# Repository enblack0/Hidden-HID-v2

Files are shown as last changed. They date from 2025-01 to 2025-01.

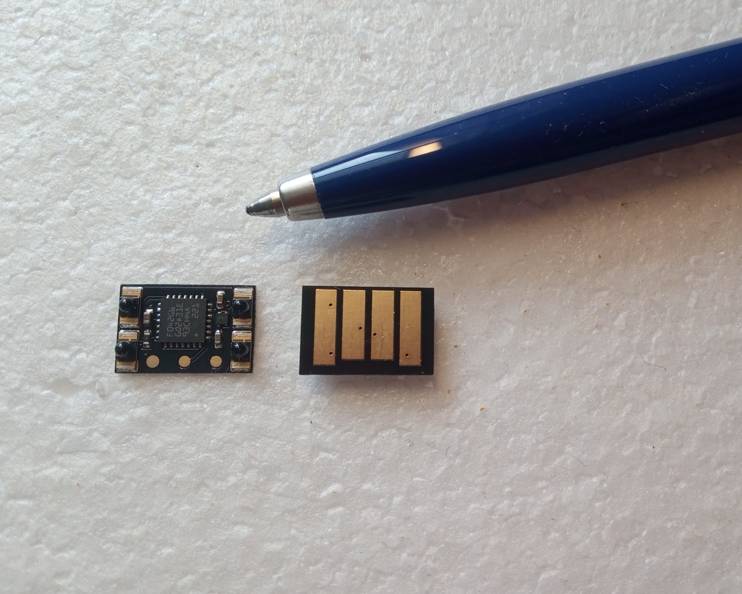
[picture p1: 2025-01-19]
photos/cover-cropped.jpg

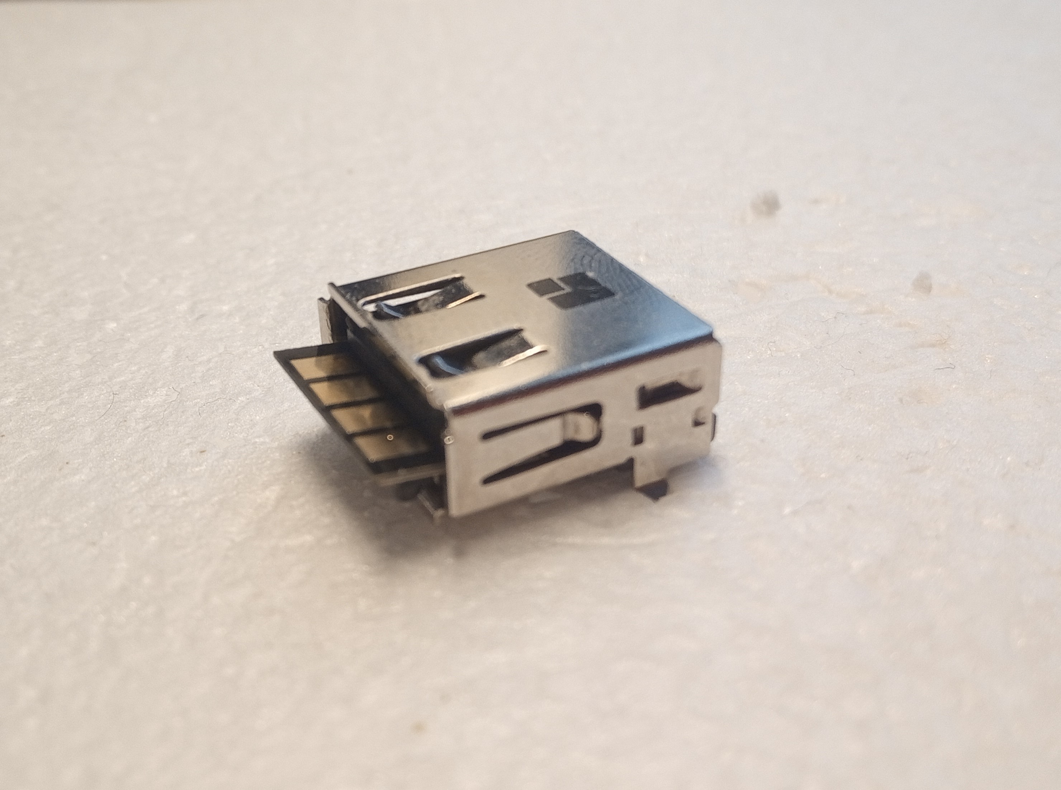
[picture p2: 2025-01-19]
photos/IMG_20250118_131920_344.jpg

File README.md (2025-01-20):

# Hidden-HID-v2
Hidden HID v2 is a tiny USB rubber ducky that can be concealed entirely inside the USB port. I have implemented various hardware improvements compared to v1.

These include: 
1. Removal of SWD programming pins to rely only on STs internal USB bootloader, which avoids the need to painstakingly solder the PCB to the STLink debugger every time I want to change the program. Now it is only necessary to bridge the BOOT0 test pad (middle) with 3V3 to select bootloader, or with GND to select application (see image below). After connecting BOOT0 to 3V3, the STM32 can then be programmed by inserting into the USB port and using the STCubeProgrammer tool to download the hex file. 
2. Layout changes to enable easier assembly of the spacer elements
3. Switching the spacer elements from LEDs with no electrical function to IR phototransistors which also provide a simple on-off remote control. This allows the device to be remotely armed and disarmed once inserted.

rev2-bot 

connect BOOT0 to GND to run application or with 3V3 to reprogram

KiCad files can be found under /KiCad, gerber and BOM separately under /Fabrication.
Under /STM32 I have uploaded a basic test firmware. This firmware waits for an IR signal, then opens a terminal and echoes hello world. You may need to tweak the paths a little to get it running on your system. 

If you are interested in purchasing this PCB, I have uploaded it to the PCBWay community. Here you can order either the bare PCB or the assembled PCB directly: https://www.pcbway.com/project/shareproject/Hidden_HID_an_invisible_USB_Rubber_Ducky_3a8cd27f.html

Also check out the project write-up on hackaday: https://hackaday.io/project/202218-hidden-hid-v2-worlds-smallest-rubber-ducky

cover-cropped



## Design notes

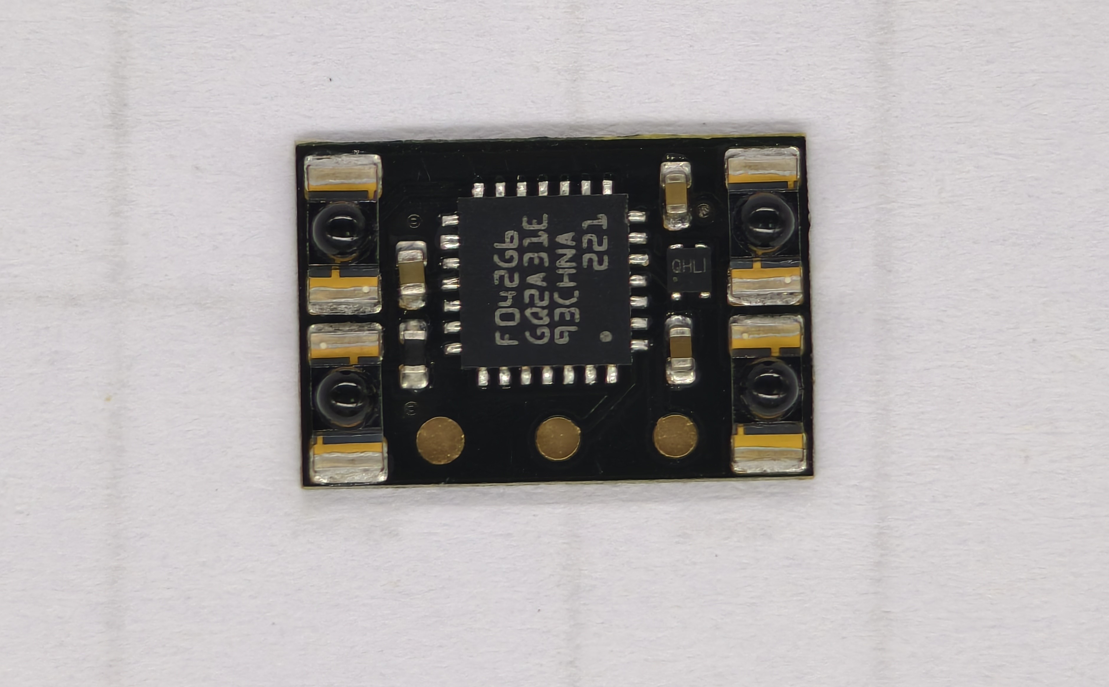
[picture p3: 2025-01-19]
photos/bot-hr.jpg

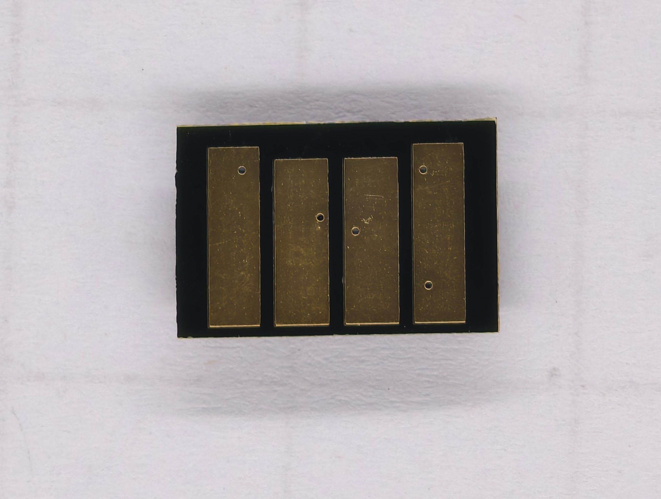
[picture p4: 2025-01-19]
photos/top-hr.jpg

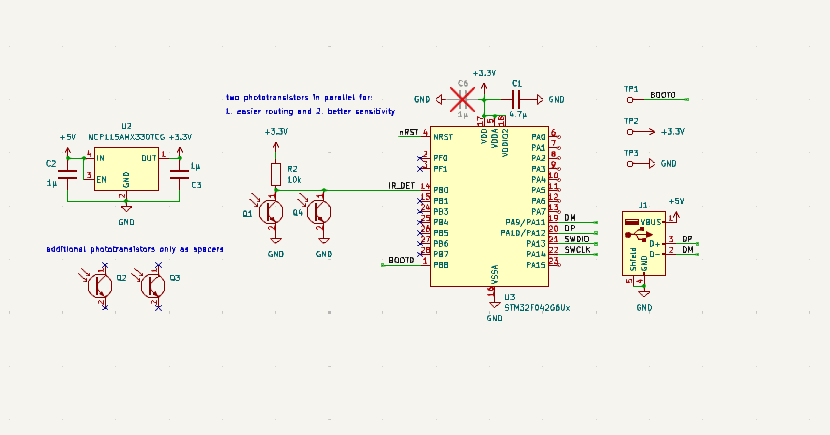
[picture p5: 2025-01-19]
photos/Screenshot 2025-01-18 160303.png

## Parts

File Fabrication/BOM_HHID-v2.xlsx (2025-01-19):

Item | Designator | Quantity | Manufacturer | Mfg Part # | Description / Value | Package / Footprint | Type | Mouser Part # | Digikey Part # | Notes
1 | C1 | 1 |  |  | CAP CER 4.7µF 10V X5R/X7R | 0402 | SMD
2 | C2, C3 | 2 |  |  | CAP CER 1µF 16V X5R/X7R | 0402 | SMD
3 | R2 | 1 |  |  | RES 10k 1% | 0402 | SMD
4 | Q1, Q2, Q3, Q4 | 4 | Würth Elektronik | 1541201NC3060 | Phototransistor IR 940nm | 1206 | SMD | 710-1541201NC3060
5 | U3 | 1 | STMicroelectronics | STM32F042G6U6 | ARM Microcontrollers - MCU Mainstream Arm Cortex-M0+ MCU 32 Kbytes Flash | UFQFPN-28 | SMD | 511-STM32F042G6U6
6 | U2 | 1 | onsemi | NCP115AMX330TCG | LDO 3.3V 300mA | XDFN-4 | SMD | 863-NCP115AMX330TCG

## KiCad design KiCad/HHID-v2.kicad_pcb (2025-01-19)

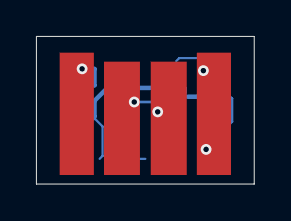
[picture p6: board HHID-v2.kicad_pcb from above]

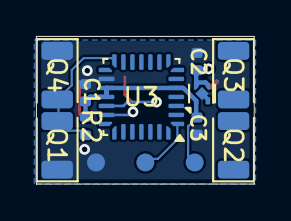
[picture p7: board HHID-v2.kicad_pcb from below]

Board: 2 copper layers, 12.1 x 8.2 mm, 14 parts (13 on the bottom side), 7 nets.

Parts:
C1: 4.7µ; C_0402_1005Metric_noSS
C2, C3: 1µ; C_0402_1005Metric_noSS
J1: USB_A; usb-PCB
Q1, Q2, Q3, Q4: Würth 1541201NC3060; LED_1206_3216Metric_IPC_C
R2: 2k2; R_0402_1005Metric_noSS
TP1, TP2, TP3: TestPoint_Pad_D0.8mm
U2: NCP115AMX330TCG; OnSemi_XDFN4-1EP_1.0x1.0mm_EP0.52x0.52mm
U3: STM32F042G6Ux; QFN-28_4x4mm_P0.5mm

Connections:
+3.3V: C1.2, C3.2, R2.1, TP2.1, U2.1 (OUT), U3.5 (VDDA), U3.17 (VDD), U3.18 (VDDIO2)
+5V: C2.1, J1.1 (VBUS), U2.3 (EN), U2.4 (IN)
/BOOT0: TP1.1, U3.1 (PB8)
/DM: J1.2 (D-), U3.19 (PA9/PA11)
/DP: J1.3 (D+), U3.20 (PA10/PA12)
/IR_DET: Q1.1 (C), Q4.1 (C), R2.2, U3.14 (PB0)
GND: C1.1, C2.2, C3.1, J1.4 (GND), Q1.2 (E), Q4.2 (E), TP3.1, U2.2 (GND), U2.5 (GND), U3.16 (VSSA)

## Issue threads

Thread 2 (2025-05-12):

How to compile?

todbot, 2025-05-12:
Hi! This is a really neat project.  But I cannot figure out how to get STMCubeIDE to load up the source and compile it?  I'm pretty experienced with other ARM-based chips (SAMD, RP2040, ESP32), but not STM32.  I've installed the latest STM32CubeIDE and have tried opening up or importing various parts of this repo with no success.  What's the process?  Is there a Makefile or similar instead?

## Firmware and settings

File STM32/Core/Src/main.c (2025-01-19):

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
/* Includes ------------------------------------------------------------------*/
#include "main.h"
#include "usb_device.h"
#include "stdio.h"
#include "../../STM32CubeIDE/Middlewares/USB_Device_Library/usbd_hid_ext.h"


/* USER CODE BEGIN PD */
#define KEYBOARD //also need to define in usbd_hid.c!

#define MOD_ALT_LEFT 0x04
#define WINKEY_LEFT 0xE3
#define ENTER 0x28
#define SPACE 0x2C
#define COMMA 0x36
#define DOT 0x37
#define K_A 0x04
#define K_B 0x05
#define K_C 0x06
#define K_D 0x07
#define K_E 0x08
#define K_G 0x0A
#define K_H 0x0B
#define K_I 0x0C
#define K_L 0x0F
#define K_M 0x10
#define K_N 0x11
#define K_O 0x12
#define K_P 0x13
#define K_R 0x15
#define K_S 0x16
#define K_T 0x17
#define K_U 0x18
#define K_V 0x19
#define K_W 0x1A

#define K_F8 0x41
#define CAPSLOCK 0x39
/* USER CODE END PD */

ADC_HandleTypeDef hadc;

/* USER CODE BEGIN PV */
volatile uint8_t capslock_;
/* USER CODE END PV */

void SystemClock_Config(void);
static void MX_GPIO_Init(void);
static void MX_ADC_Init(void);
/* USER CODE BEGIN PFP */
extern USBD_HandleTypeDef hUsbDeviceFS;
void Keyboard_SendChars(uint8_t mod, uint8_t *buf);
void Keyboard_SendSingleChar(uint8_t mod, uint8_t val);
void Keyboard_SendHelloWorld();
void Keyboard_WaitCapsLock();
void Keyboard_ShowPassword();
void Keyboard_TestADC();

typedef struct
{
	uint8_t MODIFIER;
	uint8_t RESERVED;
	uint8_t KEYCODE1;
	uint8_t KEYCODE2;
	uint8_t KEYCODE3;
	uint8_t KEYCODE4;
	uint8_t KEYCODE5;
	uint8_t KEYCODE6;
} kbdHID;

kbdHID keyboardHID = {0,0,0,0,0,0,0,0};
/* USER CODE END PFP */

/* USER CODE BEGIN 0 */
void Keyboard_SendChars(uint8_t mod, uint8_t *buf)
	{
		keyboardHID.MODIFIER = mod;
		keyboardHID.KEYCODE1 = buf[0];
		keyboardHID.KEYCODE2 = buf[1];
		keyboardHID.KEYCODE3 = buf[2];
		keyboardHID.KEYCODE4 = buf[3];
		keyboardHID.KEYCODE5 = buf[4];
		keyboardHID.KEYCODE6 = buf[5];
		USBD_HID_SendReport(&hUsbDeviceFS, &keyboardHID, sizeof (keyboardHID));
		HAL_Delay (50);

		//release
		keyboardHID.MODIFIER = 0x00;
		keyboardHID.KEYCODE1 = 0x00;
		keyboardHID.KEYCODE2 = 0x00;
		keyboardHID.KEYCODE3 = 0x00;
		keyboardHID.KEYCODE4 = 0x00;
		keyboardHID.KEYCODE5 = 0x00;
		keyboardHID.KEYCODE6 = 0x00;
		USBD_HID_SendReport(&hUsbDeviceFS, &keyboardHID, sizeof (keyboardHID));
		HAL_Delay (50);
	}

	void Keyboard_SendSingleChar(uint8_t mod, uint8_t val)
	{
		keyboardHID.MODIFIER = mod;
		keyboardHID.KEYCODE1 = val;
		USBD_HID_SendReport(&hUsbDeviceFS, &keyboardHID, sizeof (keyboardHID));
		HAL_Delay (50);

		keyboardHID.MODIFIER = 0;
		keyboardHID.KEYCODE1 = 0;
		USBD_HID_SendReport(&hUsbDeviceFS, &keyboardHID, sizeof (keyboardHID));
		HAL_Delay(50);
	}

	//open terminal and send hello world
	void Keyboard_SendHelloWorld()
	{
	    uint8_t buf[6] = {0,0,0,0,0,0};
		//winkey+r to open run utility
	    buf[0] = WINKEY_LEFT; buf[1] = K_R;
		Keyboard_SendChars(0,buf);
		HAL_Delay(100);
		//open command prompt
		buf[0] = K_C; buf[1] = K_M; buf[2] = K_D; buf[3] = ENTER;
		Keyboard_SendChars(0,buf);
		HAL_Delay(600);
		buf[0] = K_E; buf[1] = K_C; buf[2] = K_H; buf[3] = K_O; buf[4] = SPACE;
		Keyboard_SendChars(0,buf);
		buf[0] = K_H; buf[1] = K_E; buf[2] = K_L; buf[3] = 0x00; buf[4] = 0x00;
		Keyboard_SendChars(0,buf);
		buf[0] = K_L; buf[1] = K_O; buf[2] = SPACE;
		Keyboard_SendChars(0,buf);
		buf[0] = K_W; buf[1] = K_O; buf[2] = K_R; buf[3] = K_L; buf[4] = K_D; buf[5] = ENTER;
		Keyboard_SendChars(0,buf);
	}

	//check that PC is unlocked before executing by setting capslock and waiting for user to turn it off
	void Keyboard_WaitCapsLock()
	{
		//try to set capslock until it succeeds
		while(capslock_==0) {
		  Keyboard_SendSingleChar(0x00, CAPSLOCK);
		  HAL_Delay(1000);
		}
		while(capslock_==1); //wait here for user to turn off capslock
		HAL_Delay(2000);
	}

	//send ALT+F8 shortcut to display passwords being typed in
	void Keyboard_ShowPassword()
	{
		keyboardHID.MODIFIER = MOD_ALT_LEFT;
		keyboardHID.KEYCODE1 = K_F8;
		USBD_HID_SendReport(&hUsbDeviceFS, &keyboardHID, sizeof (keyboardHID));
		HAL_Delay (250);

		keyboardHID.MODIFIER = 0;
		keyboardHID.KEYCODE1 = 0;
		USBD_HID_SendReport(&hUsbDeviceFS, &keyboardHID, sizeof (keyboardHID));
		HAL_Delay(50);
	}

	//send current ADC value over USB
	void Keyboard_TestADC()
	{
		uint8_t buf[6] = {0,0,0,0,0,0};
		uint16_t adc_val = 0;
		char adc_str[6];
		HAL_ADC_Start(&hadc);
		HAL_ADC_PollForConversion(&hadc,100);
		adc_val = HAL_ADC_GetValue(&hadc);
		HAL_ADC_Stop(&hadc);
		sprintf(adc_str, "%04d", adc_val);
		for(uint8_t i=0;i<4;i++){
		  if(adc_str[i]==0x30) buf[i]=0x27; //zero case
		  else buf[i] = adc_str[i] - 0x13; //translate other digits from ASCII to HID
		  Keyboard_SendSingleChar(0,buf[i]);
		}
		Keyboard_SendSingleChar(0,ENTER);
		HAL_Delay(1000);
	}
/* USER CODE END 0 */

/**
  * @brief  The application entry point.
  * @retval int
  */
int main(void)
{

  /* MCU Configuration--------------------------------------------------------*/

  /* Reset of all peripherals, Initializes the Flash interface and the Systick. */
  HAL_Init();

  /* Configure the system clock */
  SystemClock_Config();

  /* USER CODE BEGIN SysInit */
  capslock_ = 0;
  /* USER CODE END SysInit */

  /* Initialize all configured peripherals */
  MX_GPIO_Init();
  MX_USB_DEVICE_Init();
  MX_ADC_Init();
  /* USER CODE BEGIN 2 */
  HAL_Delay(3000);
  Keyboard_WaitCapsLock();
  //HAL_Delay(10000);

  //get reference ADC value without IR by averaging 16 ADC readings over first 8 seconds
  uint16_t adc_val_ini = 0;
  for(uint8_t i = 0; i<16; i++) {
	HAL_Delay(500);
	HAL_ADC_Start(&hadc);
	HAL_ADC_PollForConversion(&hadc,100);
	adc_val_ini += HAL_ADC_GetValue(&hadc) >> 4;
	HAL_ADC_Stop(&hadc);
  }
  /* USER CODE END 2 */

  /* Infinite loop */
  /* USER CODE BEGIN WHILE */
  while (1)
  {
	  HAL_ADC_Start(&hadc);
	  HAL_ADC_PollForConversion(&hadc,100);
	  //default ADC value seems to sink quite a bit from initial during use, presumably
	  //due to temperature dependence of the photodiodes - so subtract 200 from initial value
	  //to use as reference
	  if(HAL_ADC_GetValue(&hadc) < (adc_val_ini - 200)) {
		  Keyboard_SendHelloWorld();
		  //Keyboard_ShowPassword();
	  }
	  HAL_Delay(500);
    /* USER CODE END WHILE */

    /* USER CODE BEGIN 3 */
  }
  /* USER CODE END 3 */
}

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


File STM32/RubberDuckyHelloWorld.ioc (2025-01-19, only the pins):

Mcu.UserName=STM32F042G6Ux
PA11.Signal=USB_DM
PA12.Signal=USB_DP
PA13.Signal=SYS_SWDIO
PA14.Signal=SYS_SWCLK
PB0.Signal=ADC_IN8

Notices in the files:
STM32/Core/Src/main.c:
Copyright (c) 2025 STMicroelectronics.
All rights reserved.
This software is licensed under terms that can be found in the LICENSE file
